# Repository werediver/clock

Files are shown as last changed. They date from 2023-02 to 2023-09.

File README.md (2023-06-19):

# Clock

This [Pico](https://www.raspberrypi.com/documentation/microcontrollers/raspberry-pi-pico.html)-based clock uses a dedicated oscillator for the built-in RP2040 [RTC](https://datasheets.raspberrypi.com/rp2040/rp2040-datasheet.pdf#section_rtc), displays time using seven-segment indicators, features capacitive touch-sensing buttons, and a custom built-in NiMH charging circuit.

The estimated run-time on a single charge is _one week_ (yes, _just_ one week).

<p width="100%" align="justify">
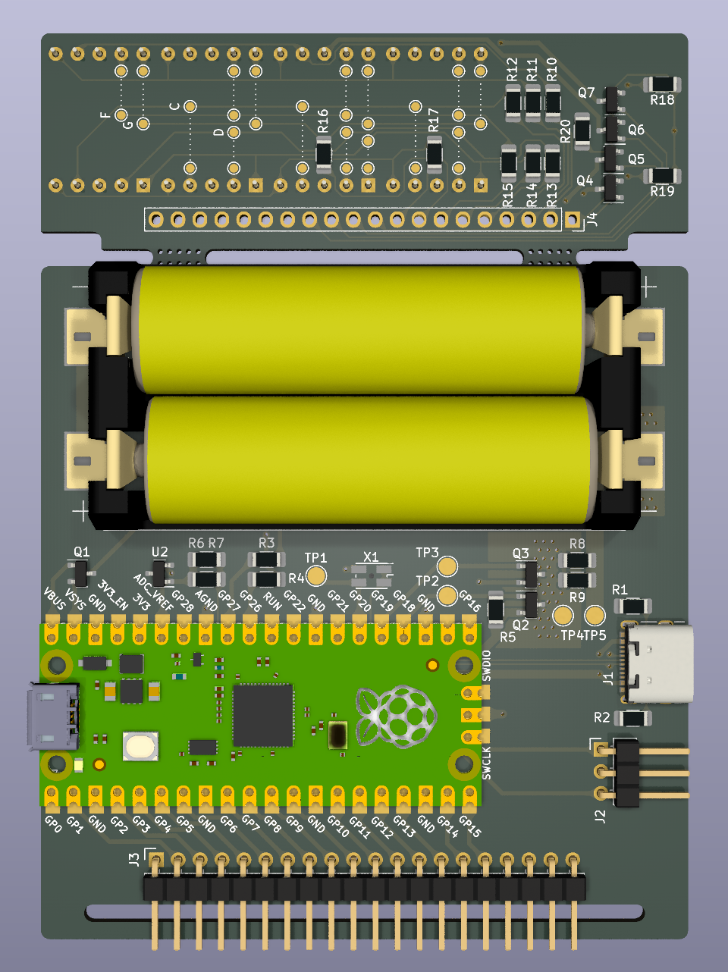
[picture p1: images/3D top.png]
PCB 3D view, top

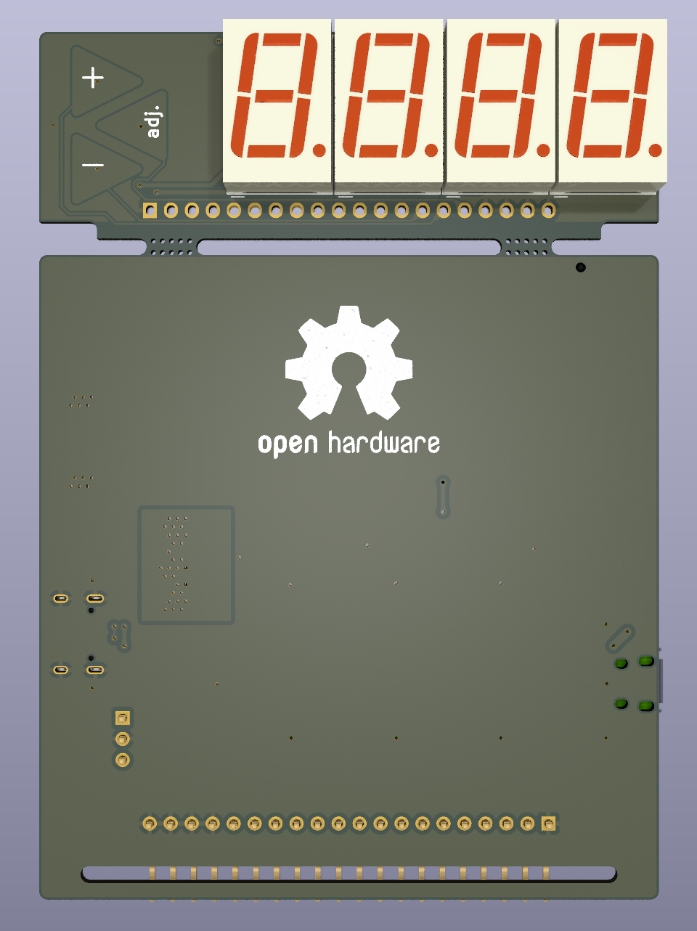
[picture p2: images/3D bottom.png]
PCB 3D view, bottom

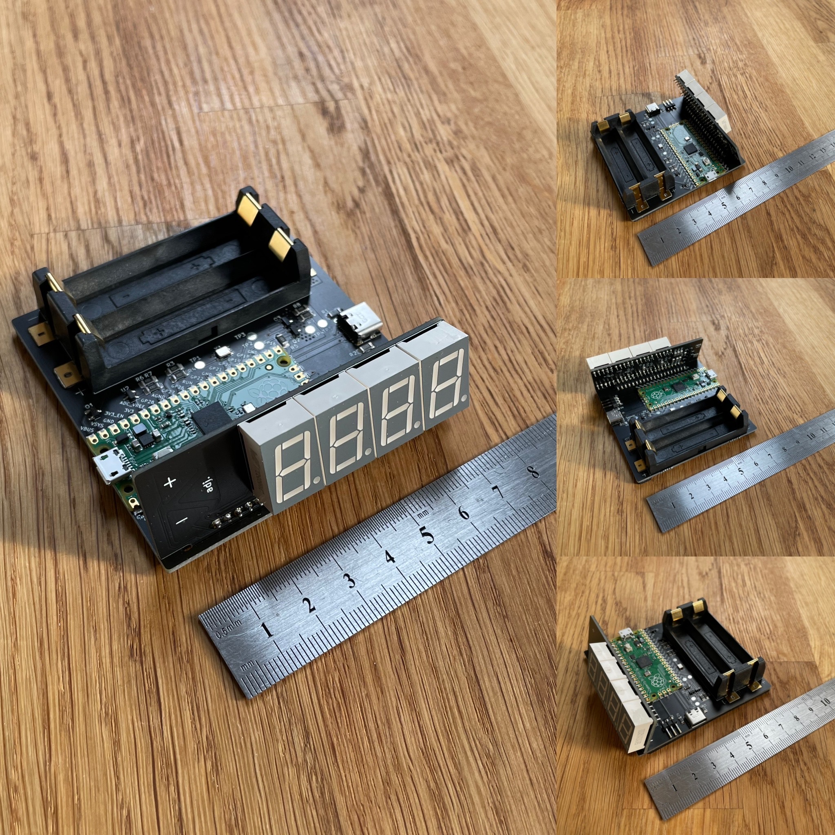
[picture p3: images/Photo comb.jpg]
Photo, combined

</p>

When assembling, refer to the [interactive BOM](https://htmlpreview.github.io/?https://github.com/werediver/clock/blob/main/KiCad/bom/ibom.html) page.

## NiMH battery charger

```mermaid
---
title: Charger state machine
---
stateDiagram-v2
    [*] --> Hold
    Hold --> Charge: ext_power && v < HIGH
    Charge --> Charged: d(v) ≤ NDV || is_adc_saturated() || is_timed_out()
    Charged --> Charge: v < HIGH
    Charge --> Hold: !ext_power
    Charged --> Hold: !ext_power
```

- [ ] Add a time-out for `v ≥ NiMH_HIGH` (1–2h?)

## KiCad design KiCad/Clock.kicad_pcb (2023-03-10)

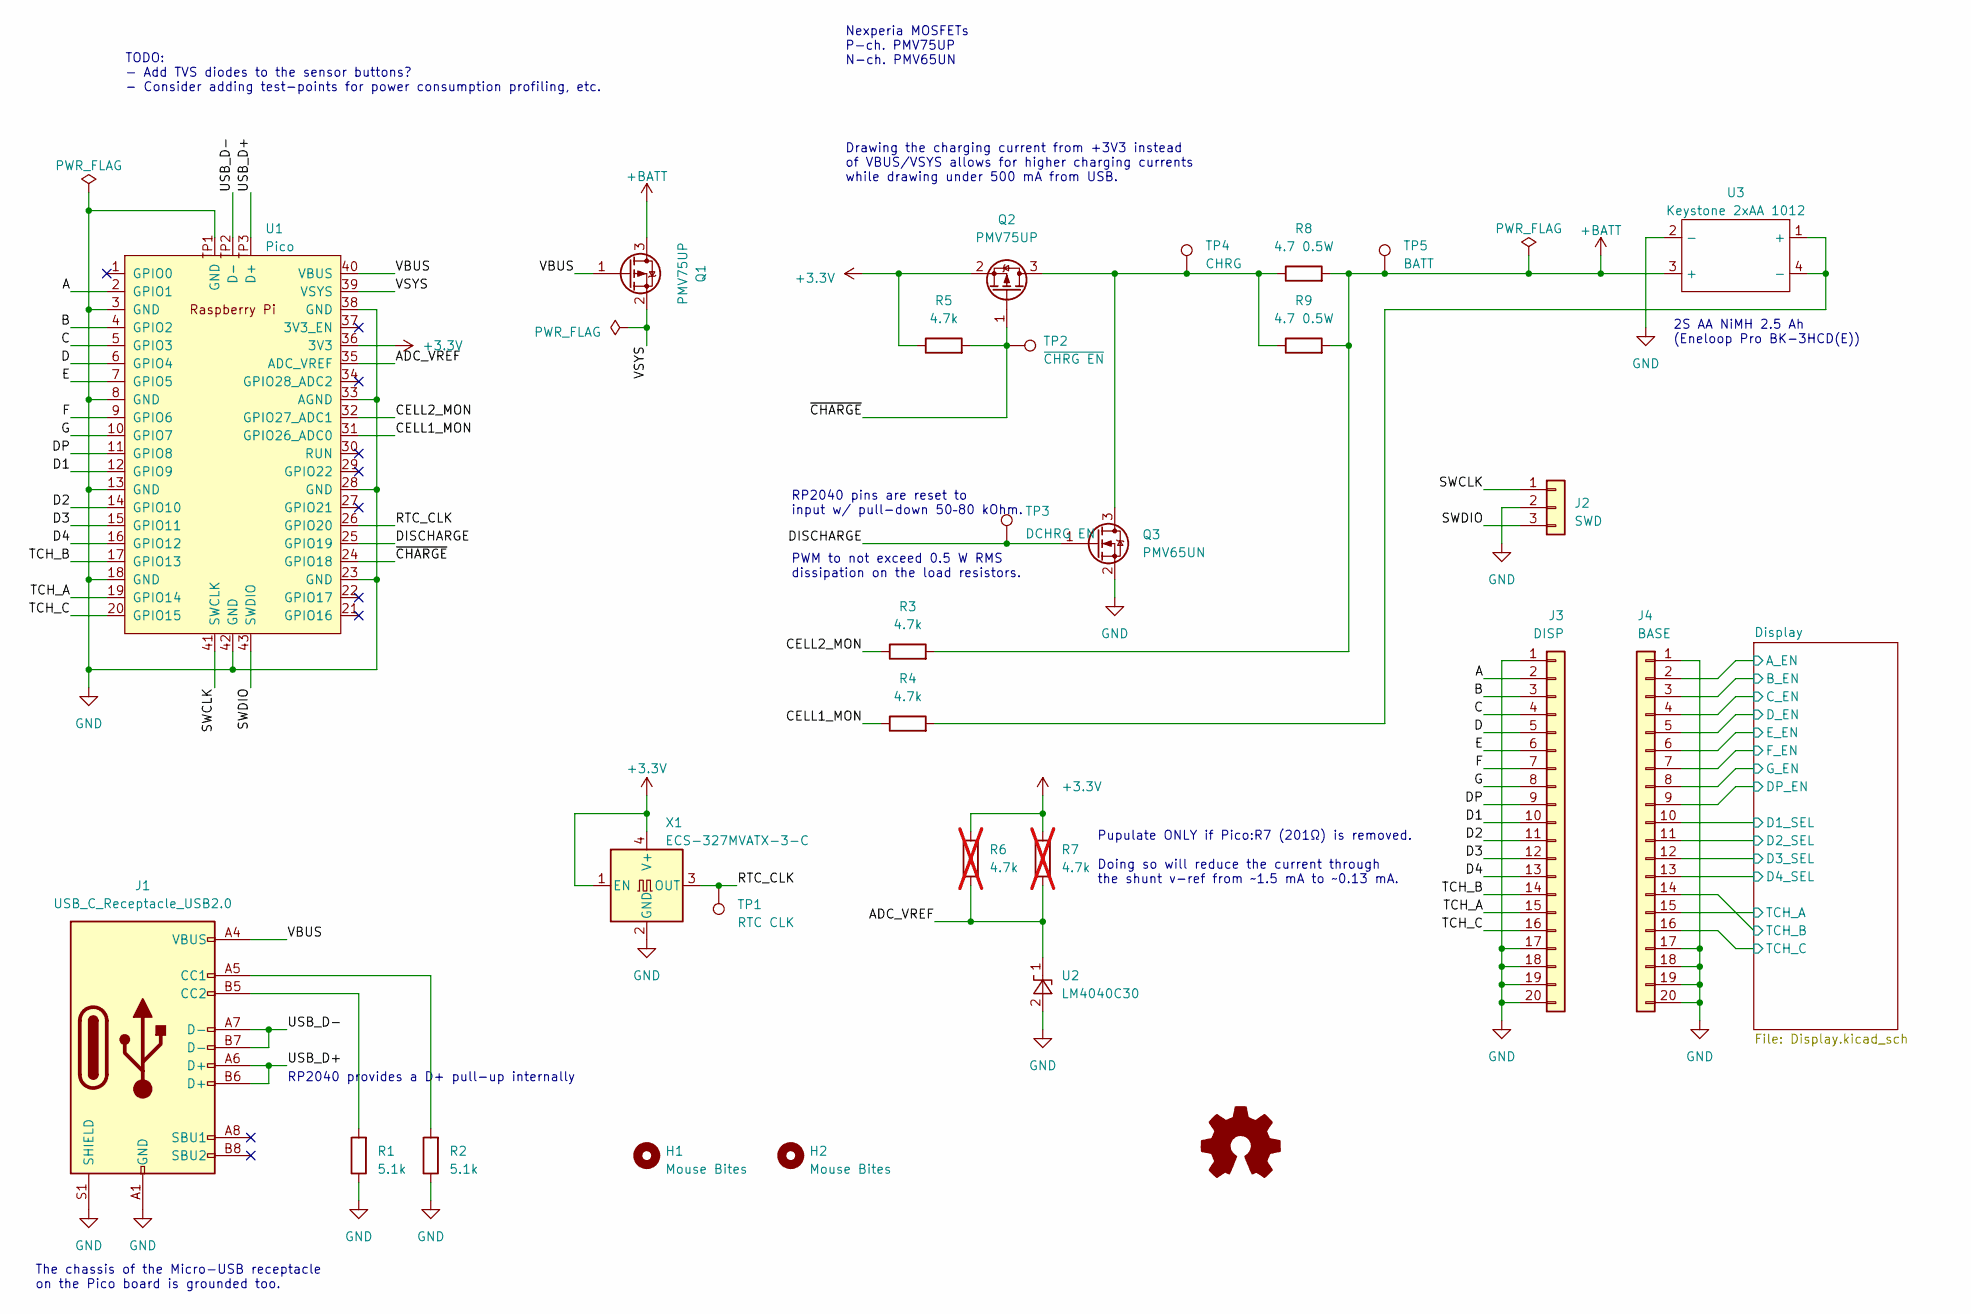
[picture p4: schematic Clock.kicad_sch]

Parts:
H1, H2: Mouse Bites; MouseBites_2x05mm
J1: USB_C_Receptacle_USB2.0; USB_C_Receptacle_GCT_USB4105-xx-A_16P_TopMnt_Horizontal
J2: SWD; PinHeader_1x03_P2.54mm_Horizontal
J3: DISP; PinHeader_1x20_P2.54mm_Horizontal
J4: BASE; PinSocket_1x20_P2.54mm_Vertical
Q1, Q2: PMV75UP; SOT-23
Q3: PMV65UN; SOT-23
R1, R2: 5.1k; R_1206_3216Metric_Pad1.30x1.75mm_HandSolder
R3, R4, R5: 4.7k; R_1206_3216Metric_Pad1.30x1.75mm_HandSolder
R6, R7: 4.7k; R_1206_3216Metric_Pad1.30x1.75mm_HandSolder; not fitted
R8, R9: 4.7 0.5W; R_1206_3216Metric_Pad1.30x1.75mm_HandSolder
SYM1: Logo_Open_Hardware_Small; OSHW-Logo2_24.3x20mm_SilkScreen
TP1: RTC CLK; TestPoint_Pad_D2.0mm
TP2: ~{CHRG EN}; TestPoint_Pad_D2.0mm
TP3: DCHRG EN; TestPoint_Pad_D2.0mm
TP4: CHRG; TestPoint_Pad_D2.0mm
TP5: BATT; TestPoint_Pad_D2.0mm
U1: Pico; RPi_Pico_SMD
U2: LM4040C30; SOT-23
U3: Keystone 2xAA 1012; BatteryHolder_Keystone_1012_2xAA
X1: ECS-327MVATX-3-C; Oscillator_SMD_EuroQuartz_XO32-4Pin_3.2x2.5mm_HandSoldering

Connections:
+3.3V: Q2.2 (S), R5.1, R6.2, R7.2, U1.36 (3V3), X1.1 (EN), X1.4 (V+)
+BATT: Q1.3 (D), R3.2, R8.2, R9.2, TP5.1, U3.3 (+)
/A: J3.2, U1.2 (GPIO1)
/ADC_VREF: R6.1, R7.1, U1.35 (ADC_VREF), U2.1 (K)
/B: J3.3, U1.4 (GPIO2)
/C: J3.4, U1.5 (GPIO3)
/CELL1_MON: R4.1, U1.31 (GPIO26_ADC0)
/CELL2_MON: R3.1, U1.32 (GPIO27_ADC1)
/D: J3.5, U1.6 (GPIO4)
/D1: J3.10, U1.12 (GPIO9)
/D2: J3.11, U1.14 (GPIO10)
/D3: J3.12, U1.15 (GPIO11)
/D4: J3.13, U1.16 (GPIO12)
/DISCHARGE: Q3.1 (G), TP3.1, U1.25 (GPIO19)
/DP: J3.9, U1.11 (GPIO8)
/Display/A_EN: J4.2; also elsewhere on the board
/Display/B_EN: J4.3; also elsewhere on the board
/Display/C_EN: J4.4; also elsewhere on the board
/Display/D1_SEL: J4.10; also elsewhere on the board
/Display/D2_SEL: J4.11; also elsewhere on the board
/Display/D3_SEL: J4.12; also elsewhere on the board
/Display/D4_SEL: J4.13; also elsewhere on the board
/Display/DP_EN: J4.9; also elsewhere on the board
/Display/D_EN: J4.5; also elsewhere on the board
/Display/E_EN: J4.6; also elsewhere on the board
/Display/F_EN: J4.7; also elsewhere on the board
/Display/G_EN: J4.8; also elsewhere on the board
/E: J3.6, U1.7 (GPIO5)
/F: J3.7, U1.9 (GPIO6)
/G: J3.8, U1.10 (GPIO7)
/RTC_CLK: TP1.1, U1.26 (GPIO20), X1.3 (OUT)
/SWCLK: J2.1, U1.41 (SWCLK)
/SWDIO: J2.3, U1.43 (SWDIO)
/TCH_A: J3.15, U1.19 (GPIO14)
/TCH_B: J3.14, U1.17 (GPIO13)
/TCH_C: J3.16, U1.20 (GPIO15)
/USB_D+: J1.A6 (D+), J1.B6 (D+), U1.TP3 (D+)
/USB_D-: J1.A7 (D-), J1.B7 (D-), U1.TP2 (D-)
/VBUS: J1.A4 (VBUS), J1.A9 (VBUS), J1.B4 (VBUS), J1.B9 (VBUS), Q1.1 (G), U1.40 (VBUS)
/VSYS: Q1.2 (S), U1.39 (VSYS)
/~CHARGE: Q2.1 (G), R5.2, TP2.1, U1.24 (GPIO18)
GND: J1.A1 (GND), J1.A12 (GND), J1.B1 (GND), J1.B12 (GND), J1.S1 (SHIELD), J2.2, J3.1, J3.17, J3.18, J3.19, J3.20, J4.1, J4.17, J4.18, J4.19, J4.20, Q3.2 (S), R1.1, R2.1, U1.3 (GND), U1.8 (GND), U1.13 (GND), U1.18 (GND), U1.23 (GND), U1.28 (GND), U1.33 (AGND), U1.38 (GND), U1.42 (GND), U1.TP1 (GND), U2.2 (A), U3.2 (-), X1.2 (GND); also elsewhere on the board
unnamed: J1.A5 (CC1), R2.2
unnamed: J1.B5 (CC2), R1.2
unnamed: Q2.3 (D), Q3.3 (D), R8.1, R9.1, TP4.1
unnamed: R4.2, U3.1 (+), U3.4 (-)

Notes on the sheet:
2S AA NiMH 2.5 Ah (Eneloop Pro BK-3HCD(E))
RP2040 provides a D+ pull-up internally
PWM to not exceed 0.5 W RMS dissipation on the load resistors.
RP2040 pins are reset to input w/ pull-down 50–80 kOhm.
Nexperia MOSFETs P-ch. PMV75UP N-ch. PMV65UN
Pupulate ONLY if Pico:R7 (201Ω) is removed. Doing so will reduce the current through the shunt v-ref from ~1.5 mA to ~0.13 mA.
Drawing the charging current from +3V3 instead of VBUS/VSYS allows for higher charging currents while drawing under 500 mA from USB.
TODO: - Add TVS diodes to the sensor buttons? - Consider adding test-points for power consumption profiling, etc.
The chassis of the Micro-USB receptacle on the Pico board is grounded too.

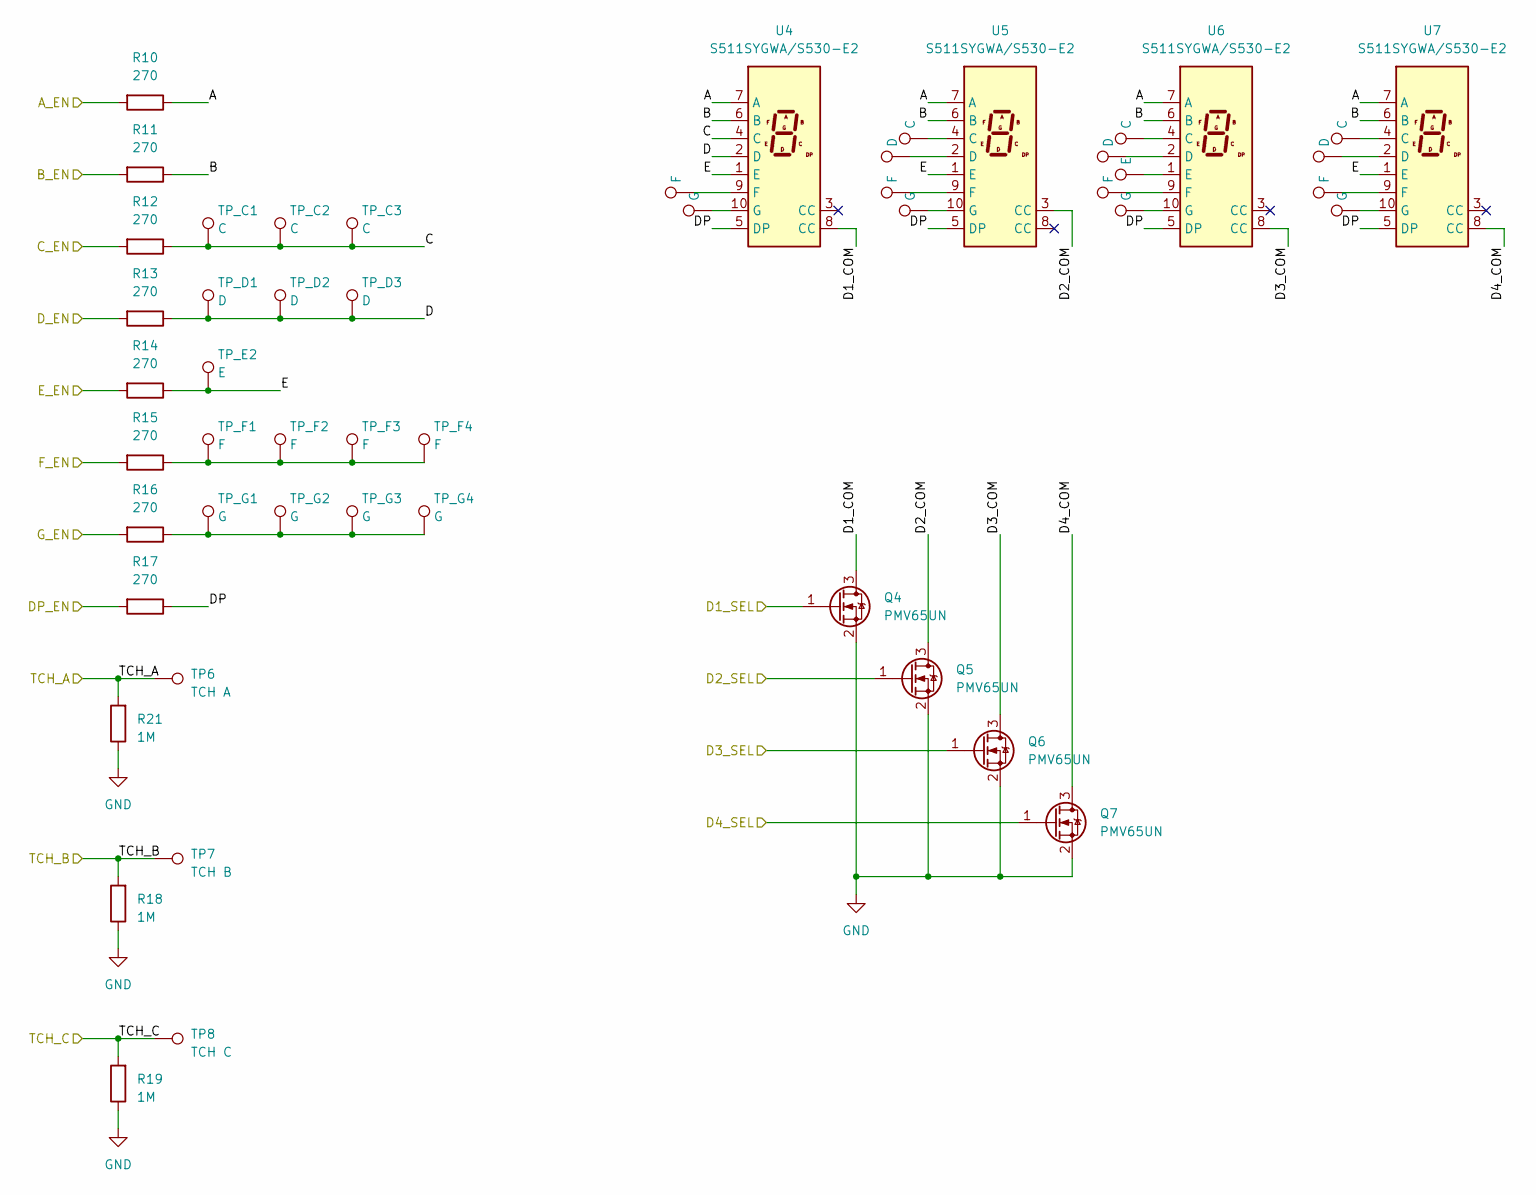
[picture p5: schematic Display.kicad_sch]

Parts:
Q4, Q5, Q6, Q7: PMV65UN; SOT-23
R10, R11, R12, R13, R14, R15, R16, R17: 270; R_1206_3216Metric_Pad1.30x1.75mm_HandSolder
R18, R19, R21: 1M; R_1206_3216Metric_Pad1.30x1.75mm_HandSolder
TP6: TCH A; TouchPad
TP7: TCH B; TouchPad
TP8: TCH C; TouchPad
TP_C1, TP_C2, TP_C3, TP_C6, TP_C7, TP_C8: C; TestPoint_Pad_D1.0mm
TP_D1, TP_D2, TP_D3, TP_D6, TP_D7, TP_D8: D; TestPoint_Pad_D1.0mm
TP_E2, TP_E7: E; TestPoint_Pad_D1.0mm
TP_F1, TP_F2, TP_F3, TP_F4, TP_F5, TP_F6, TP_F7, TP_F8: F; TestPoint_Pad_D1.0mm
TP_G1, TP_G2, TP_G3, TP_G4, TP_G5, TP_G6, TP_G7, TP_G8: G; TestPoint_Pad_D1.0mm
U4, U5, U6, U7: S511SYGWA/S530-E2; D1X8K

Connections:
/Display/A: R10.1, U4.7 (A), U5.7 (A), U6.7 (A), U7.7 (A)
/Display/A_EN: R10.2; also elsewhere on the board
/Display/B: R11.1, U4.6 (B), U5.6 (B), U6.6 (B), U7.6 (B)
/Display/B_EN: R11.2; also elsewhere on the board
/Display/C: R12.1, TP_C1.1, TP_C2.1, TP_C3.1, U4.4 (C)
/Display/C_EN: R12.2; also elsewhere on the board
/Display/D: R13.1, TP_D1.1, TP_D2.1, TP_D3.1, U4.2 (D)
/Display/D1_COM: Q4.3 (D), U4.8 (CC)
/Display/D1_SEL: Q4.1 (G); also elsewhere on the board
/Display/D2_COM: Q5.3 (D), U5.3 (CC)
/Display/D2_SEL: Q5.1 (G); also elsewhere on the board
/Display/D3_COM: Q6.3 (D), U6.8 (CC)
/Display/D3_SEL: Q6.1 (G); also elsewhere on the board
/Display/D4_COM: Q7.3 (D), U7.8 (CC)
/Display/D4_SEL: Q7.1 (G); also elsewhere on the board
/Display/DP: R17.1, U4.5 (DP), U5.5 (DP), U6.5 (DP), U7.5 (DP)
/Display/DP_EN: R17.2; also elsewhere on the board
/Display/D_EN: R13.2; also elsewhere on the board
/Display/E: R14.1, TP_E2.1, U4.1 (E), U5.1 (E), U7.1 (E)
/Display/E_EN: R14.2; also elsewhere on the board
/Display/F_EN: R15.2; also elsewhere on the board
/Display/G_EN: R16.2; also elsewhere on the board
GND: Q4.2 (S), Q5.2 (S), Q6.2 (S), Q7.2 (S), R18.1, R19.1; also elsewhere on the board
unnamed: R15.1, TP_F1.1, TP_F2.1, TP_F3.1, TP_F4.1
unnamed: R16.1, TP_G1.1, TP_G2.1, TP_G3.1, TP_G4.1
unnamed: TP_F5.1, U4.9 (F)
unnamed: TP_G5.1, U4.10 (G)
unnamed: TP_C6.1, U5.4 (C)
unnamed: TP_D6.1, U5.2 (D)
unnamed: TP_F6.1, U5.9 (F)
unnamed: TP_G6.1, U5.10 (G)
unnamed: TP_C7.1, U6.4 (C)
unnamed: TP_D7.1, U6.2 (D)
unnamed: TP_E7.1, U6.1 (E)
unnamed: TP_F7.1, U6.9 (F)
unnamed: TP_G7.1, U6.10 (G)
unnamed: TP_C8.1, U7.4 (C)
unnamed: TP_D8.1, U7.2 (D)
unnamed: TP_F8.1, U7.9 (F)
unnamed: TP_G8.1, U7.10 (G)

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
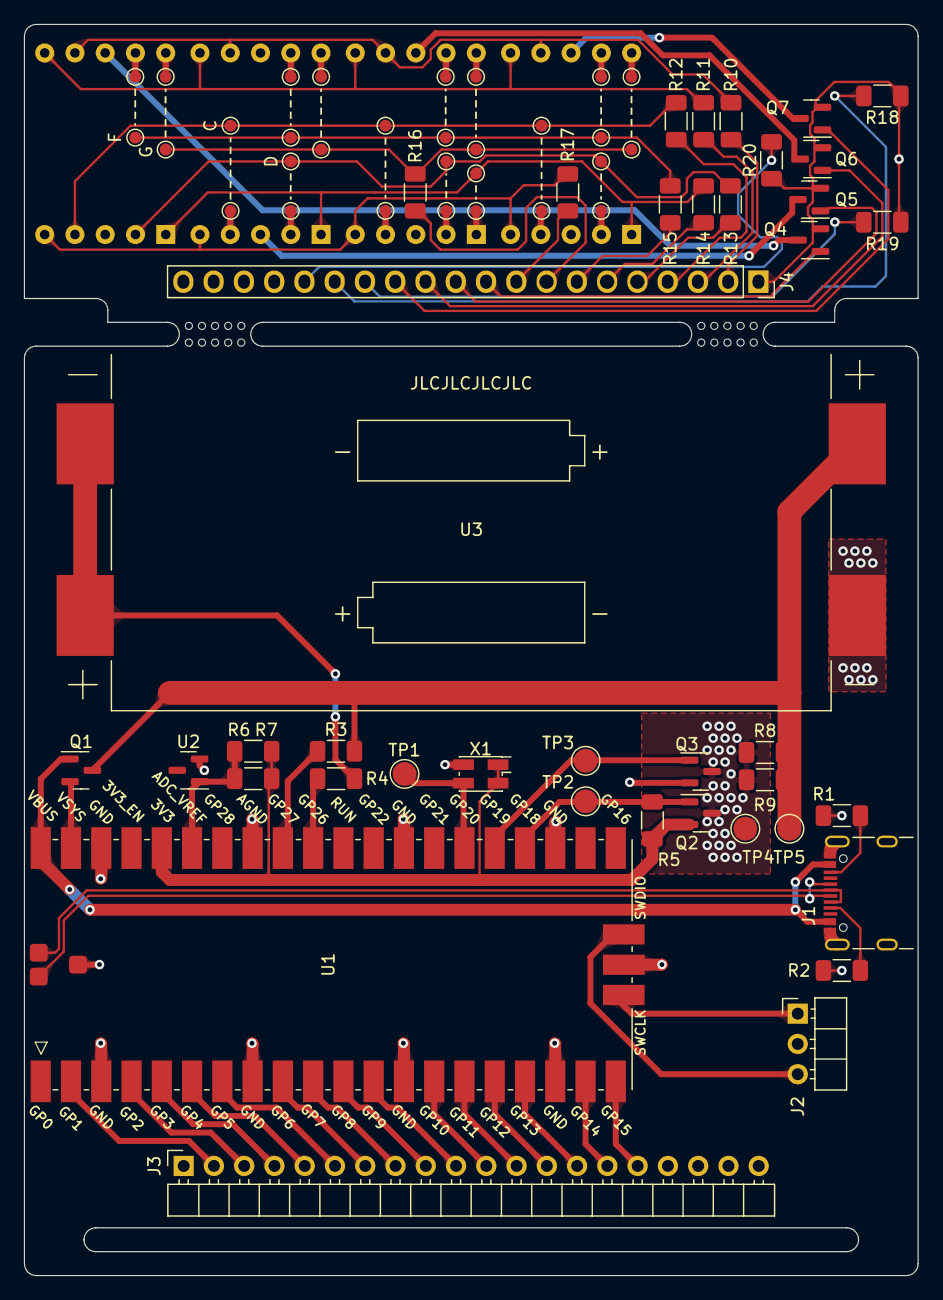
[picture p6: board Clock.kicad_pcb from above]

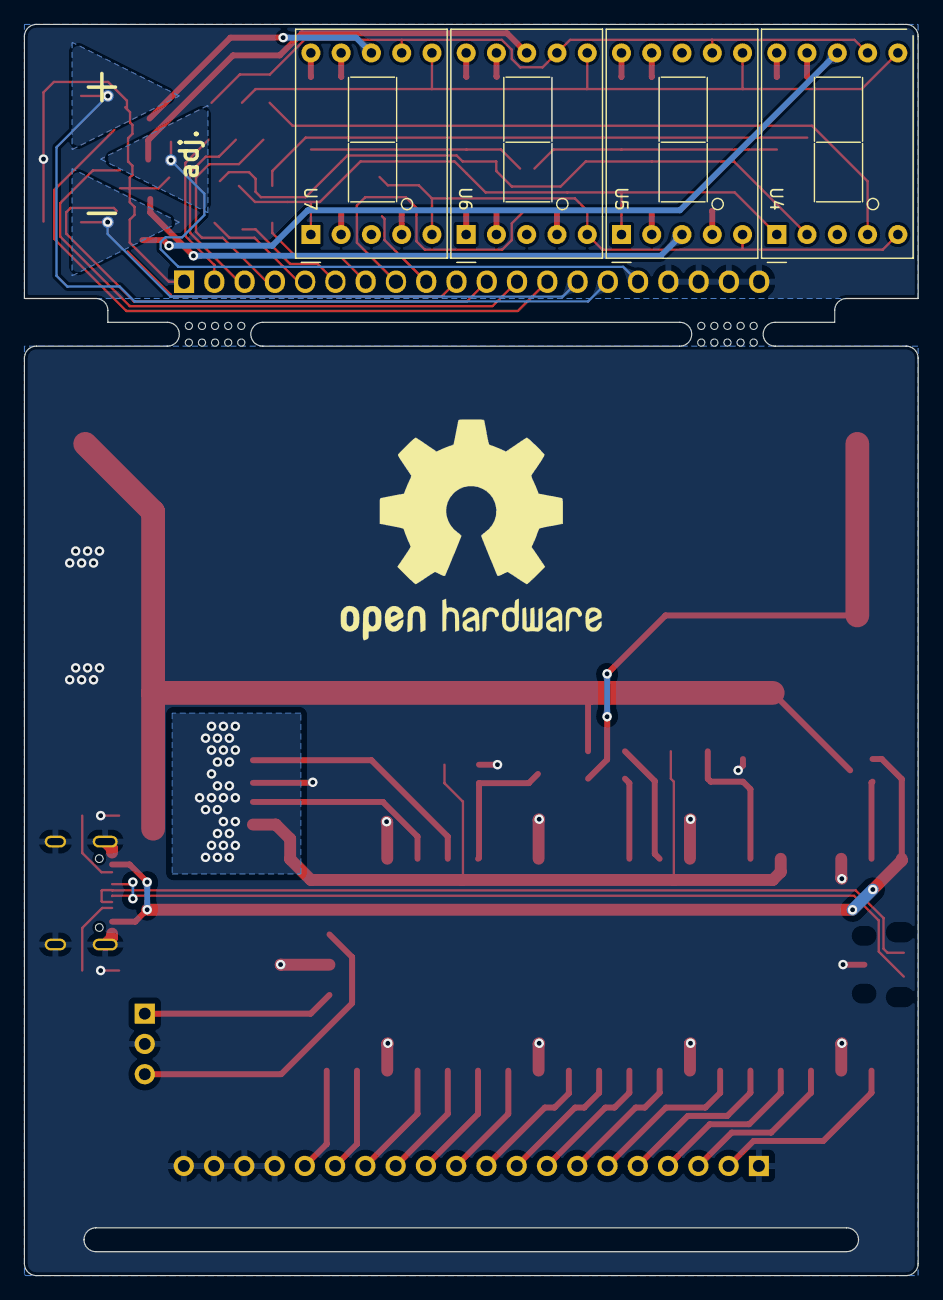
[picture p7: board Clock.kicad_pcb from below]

Board: 2 copper layers, 75.0 x 105.0 mm, 80 parts (8 on the bottom side), 76 nets.

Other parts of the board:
R20: 1M; R_1206_3216Metric_Pad1.30x1.75mm_HandSolder

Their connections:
GND: R20.1; also elsewhere on the board

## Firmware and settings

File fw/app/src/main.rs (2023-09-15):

#![no_std]
#![no_main]

extern crate alloc;

use alloc::boxed::Box;
use core::panic::PanicInfo;
use embedded_hal::{
    digital::v2::{InputPin, OutputPin},
    prelude::_embedded_hal_adc_OneShot,
};

use app_core::{
    action::Action,
    common::Duration,
    features::charger::ChargerAction,
    state::State,
    task::{scheduler::Scheduler, FnTask, NextRun, Task},
};
use embedded_alloc::Heap;
use rp_pico::{
    entry,
    hal::pac,
    hal::{self, gpio::PinState},
};
use rtt_target::{rprintln, rtt_init_print};

use crate::{
    display::{seg_disp_configure, seg_disp_update},
    uptime::Uptime,
};

mod display;
mod uptime;
mod uptime_delay;

#[entry]
fn main() -> ! {
    rtt_init_print!();
    init_heap();

    let mut pac = pac::Peripherals::take().unwrap();
    let core = pac::CorePeripherals::take().unwrap();

    let mut watchdog = hal::Watchdog::new(pac.WATCHDOG);

    let clocks = hal::clocks::init_clocks_and_plls(
        rp_pico::XOSC_CRYSTAL_FREQ,
        pac.XOSC,
        pac.CLOCKS,
        pac.PLL_SYS,
        pac.PLL_USB,
        &mut pac.RESETS,
        &mut watchdog,
    )
    .ok()
    .unwrap();

    let sio = hal::Sio::new(pac.SIO);

    let pins = rp_pico::Pins::new(
        pac.IO_BANK0,
        pac.PADS_BANK0,
        sio.gpio_bank0,
        &mut pac.RESETS,
    );

    let rtc = hal::rtc::RealTimeClock::new(
        pac.RTC,
        clocks.rtc_clock,
        &mut pac.RESETS,
        hal::rtc::DateTime {
            year: 2023,
            month: 4,
            day: 7,
            day_of_week: hal::rtc::DayOfWeek::Friday,
            hour: 9,
            minute: 1,
            second: 0,
        },
    )
    .unwrap();

    let uptime = Uptime::new(core.SYST, 5);

    fn adc_f32(value: u16) -> f32 {
        const ADC_MAX: u16 = 0x0fff;
        const ADC_VREF: f32 = 3.0;

        ADC_VREF * value as f32 / ADC_MAX as f32
    }

    let mut adc = hal::Adc::new(pac.ADC, &mut pac.RESETS);
    let mut bat_v1_pin = pins.gpio26.into_floating_input();
    let mut bat_v2_pin = pins.gpio27.into_floating_input();

    let ext_power_detect_pin = pins.vbus_detect.into_floating_input();

    let mut ncharge_pin = pins.gpio18.into_push_pull_output_in_state(PinState::High);

    let pac = unsafe { pac::Peripherals::steal() };
    seg_disp_configure(&pac.IO_BANK0, &pac.SIO);

    let app_display = app_core::features::display::Display::default();
    let mut app_charger = app_core::features::charger::Charger::default();

    let mut scheduler = Scheduler::<State, Action>::new([
        Box::new(FnTask::new(move |state: &mut State| {
            let now = rtc.now().unwrap();

            state.rtc = app_core::state::RTC {
                hour: now.hour,
                minute: now.minute,
                second: now.second,
            };

            (None, NextRun::After(Duration::from_ticks(200_000)))
        })) as _,
        Box::new(app_display) as _,
        Box::new(FnTask::new(move |state: &mut State| {
            let mut sum1 = 0;
            let mut sum2 = 0;
            const N: u16 = 16;
            for _ in 0..N {
                let v1: u16 = adc.read(&mut bat_v1_pin).unwrap();
                sum1 += v1;
                let v2: u16 = adc.read(&mut bat_v2_pin).unwrap();
                sum2 += v2;
            }
            sum2 -= sum1;
            let v1 = adc_f32(sum1) / N as f32;
            let v2 = adc_f32(sum2) / N as f32;

            state.bat_voltage = (v1, v2);
            state.ext_power = ext_power_detect_pin.is_high().unwrap();

            app_charger.run(state)
        })) as _,
    ]);

    let mut state = State::default();

    loop {
        if let Some(action) = scheduler.run(uptime.get_instant(), &mut state) {
            match action {
                Action::Display(action) => match action {
                    seg_disp::disp::Action::Render(c, i) => {
                        seg_disp_update(c, i, &pac.SIO);
                    }
                },
                Action::Battery(action) => match action {
                    ChargerAction::Charge => {
                        ncharge_pin.set_low().unwrap();
                    }
                    ChargerAction::Hold => {
                        ncharge_pin.set_high().unwrap();
                    }
                },
            }
        }
    }
}

#[global_allocator]
static HEAP: Heap = Heap::empty();

fn init_heap() {
    use core::mem::MaybeUninit;
    const HEAP_SIZE: usize = 64 * 1024;
    static mut HEAP_MEM: [MaybeUninit<u8>; HEAP_SIZE] = [MaybeUninit::uninit(); HEAP_SIZE];
    unsafe { HEAP.init(HEAP_MEM.as_ptr() as usize, HEAP_SIZE) }
}

#[panic_handler]
fn panic(info: &PanicInfo) -> ! {
    rprintln!("{}", info);
    loop {
        cortex_m::asm::wfi();
    }
}

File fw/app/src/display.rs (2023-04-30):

use rp_pico::pac;
use seg_disp::char7dp::Char7DP;

const GPIO_SEG_OFFSET: u32 = 1;
const GPIO_SEL_OFFSET: u32 = 9;

pub fn seg_disp_configure(io_bank0: &pac::IO_BANK0, sio: &pac::SIO) {
    for i in (GPIO_SEG_OFFSET..(GPIO_SEG_OFFSET + 8)).chain(GPIO_SEL_OFFSET..(GPIO_SEL_OFFSET + 4))
    {
        const GPIO_FUNC_SIO: u8 = 5;
        io_bank0.gpio[i as usize]
            .gpio_ctrl
            .write(|w| unsafe { w.funcsel().bits(GPIO_FUNC_SIO) });
    }
    sio.gpio_oe_set
        .write(|w| unsafe { w.bits(0xff << GPIO_SEG_OFFSET | 0x0f << GPIO_SEL_OFFSET) });
}

pub fn seg_disp_update(char7dp: Char7DP, digit_index: usize, sio: &pac::SIO) {
    sio.gpio_out_set.write(|w| unsafe {
        w.bits(
            (char7dp.state() as u32) << GPIO_SEG_OFFSET
                | (1 << digit_index & 0x0f) << GPIO_SEL_OFFSET,
        )
    });
    sio.gpio_out_clr.write(|w| unsafe {
        w.bits(
            (!char7dp.state() as u32) << GPIO_SEG_OFFSET
                | (!(1 << digit_index) & 0x0f) << GPIO_SEL_OFFSET,
        )
    });
}

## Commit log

2023-02-27 A completed KiCad project (may still receive minor updates)
    [Clock.kicad_pcb, Clock.kicad_sch, Display.kicad_sch]
2023-02-27 Add teardrops
    [Clock.kicad_pcb]
2023-02-27 Update README, add 3D renders of the PCB
2023-02-27 Adjust the PCB for fabrication
    [Clock.kicad_pcb, Clock.kicad_sch]
2023-03-01 Make sure all Pico SM pads belong to "F.Paste" layer
    [Clock.kicad_pcb]
2023-03-10 Attach the 3D model of Pico (again), update TODOs, update ".gitignore"
    [Clock.kicad_pcb, Clock.kicad_sch]
2023-03-31 Update the charge-discharge current limiting resistors from 4.7R to 5.6R (what I had in stock when assembling the boards)
    [Clock.kicad_sch]
2023-03-31 Add the interactive BOM files
2023-03-31 Add a photo and a link to the interactive BOM to the README
2023-03-31 Fix the link to the interactive BOM, update image alignment in README
2023-04-02 Add firmware code with a basic display driver
2023-06-19 Add battery charging logic
2023-09-15 Add charge indication, turn display off when depleted
